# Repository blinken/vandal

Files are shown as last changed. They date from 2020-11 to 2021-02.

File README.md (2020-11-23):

# vandal
### A lighting and fan control system for campervans (or anything else)

vandal is an ESP32-based 10-channel smart switch module with LoRa, CANBus, a
display, and a rotary encoder. For 12-24V DC systems, intended to control
camper or RV lighting. It features

 * 7 switched-positive output channels, capable of each sourcing 5A at Vin (up to 27V) . All channels support fade, blink, breathe modes via an SX1509 driver.
 * 3 switched-negative channels, capable of each sinking 200mA at up to 30V.
 * 6 protected IO lines, 5V-tolerant and operating at a 3.3V logic level
 * CANBus interface (via a SN65HVD230 transceiver)
 * Protected 1Wire bus, operating at 5V, for temperature sensors (DS1820B and others)
 * LoRa transceiver (HopeRF RFM95) with SMA antenna connection
 * USB programming for the ESP32 (using a FT232R)
 * Numeric/text display: footprints and headers to support 2x [Adafruit 0.54" LED backpacks](https://learn.adafruit.com/adafruit-led-backpack/0-54-alphanumeric) 
 * 8x32 LED matrix: footprints and headers to support 4x MAX7219-based 8x8 LED arrays [Amazon](https://amzn.to/3kYg7Mb) [AliExpress 1](https://www.aliexpress.com/item/32580532205.html) [AliExpress 2](https://www.aliexpress.com/item/33038259447.html)
 * Rotary (quadrature) encoder to allow control by the user
 * Protected power supply supporting 12V and 24V lead-acid and LiFePO4 battery systems

Protected lines feature diode clamping to 5V and 0V, and high-current lines
include TVS diodes on the output to protect against overvoltage and back-EMF.
The input has reverse polarity protection. All outputs (and the input) are
individually fused.

This project is a work in progress, and the software for the ESP32 doesn't
exist yet. It's intended to control LED lighting in my van, and is a bit of an
excuse to play with CANBus and the RFM95 LoRa module.

The PCB was created in KiCad. I have a few spare - if you're interested, [shoot
me an email](mailto:blinken@gmail.com) and I can post you one for a small fee.
Alternatively, the gerber files are available [here](https://github.com/blinken/vandal/blob/main/pcb/van-1.0-gerber/van.zip).

The hardware and software for this project are copyright 2020 Patrick Coleman.
They are released under the GNU General Public License, version 3.0.

## Schematic and board renders

See this [spreadsheet](https://docs.google.com/spreadsheets/d/1M1I1nklSd06B-7MHDgoApl8QgARcywJm6RRHqY701iw/edit?usp=sharing) for the BOM for board revision v1.0.

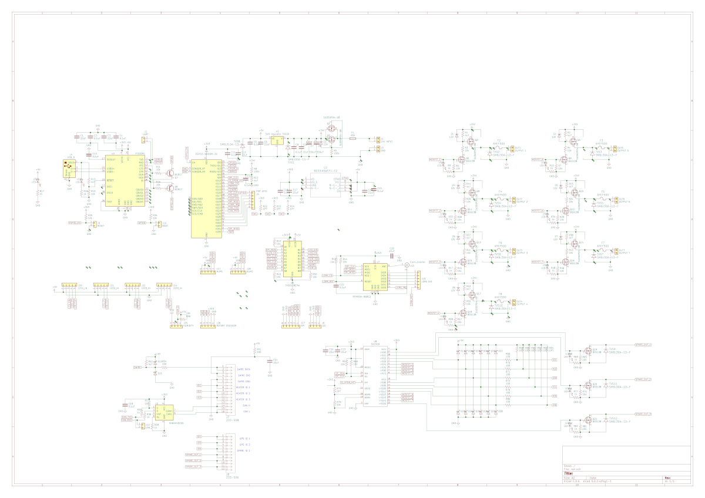
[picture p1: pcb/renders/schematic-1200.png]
schematic

[Full size PNG](https://raw.githubusercontent.com/blinken/vandal/main/pcb/renders/schematic.png) [PDF](https://github.com/blinken/vandal/raw/main/pcb/renders/schematic.pdf)

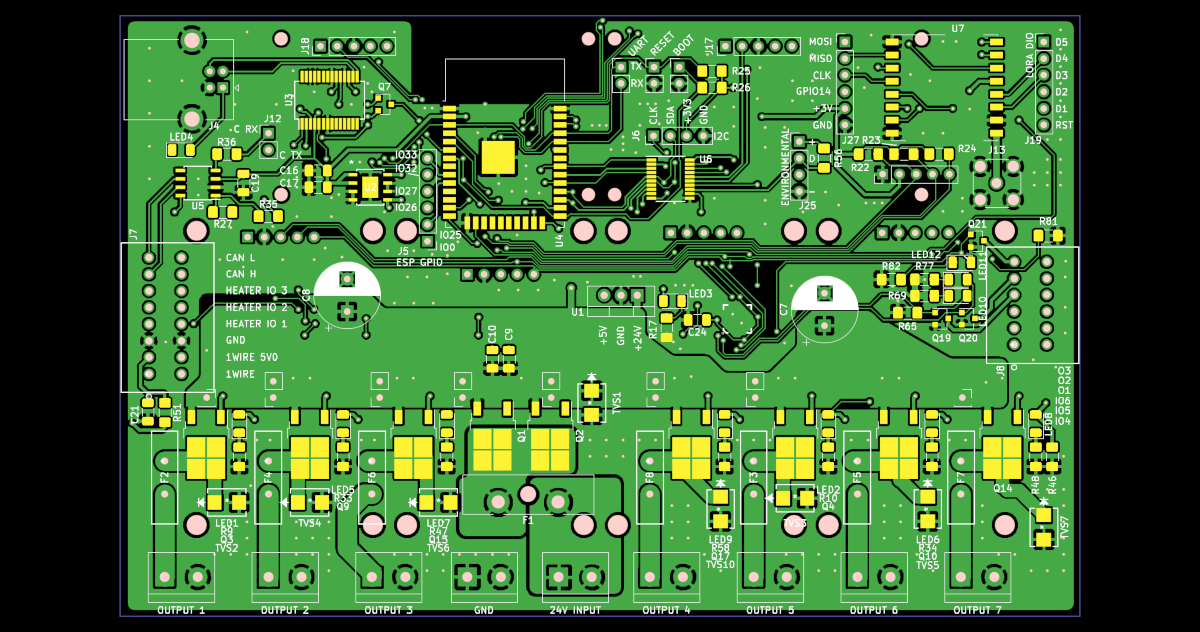
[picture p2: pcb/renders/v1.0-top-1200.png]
board top

[Full size PNG](https://raw.githubusercontent.com/blinken/vandal/main/pcb/renders/v1.0-top.png)

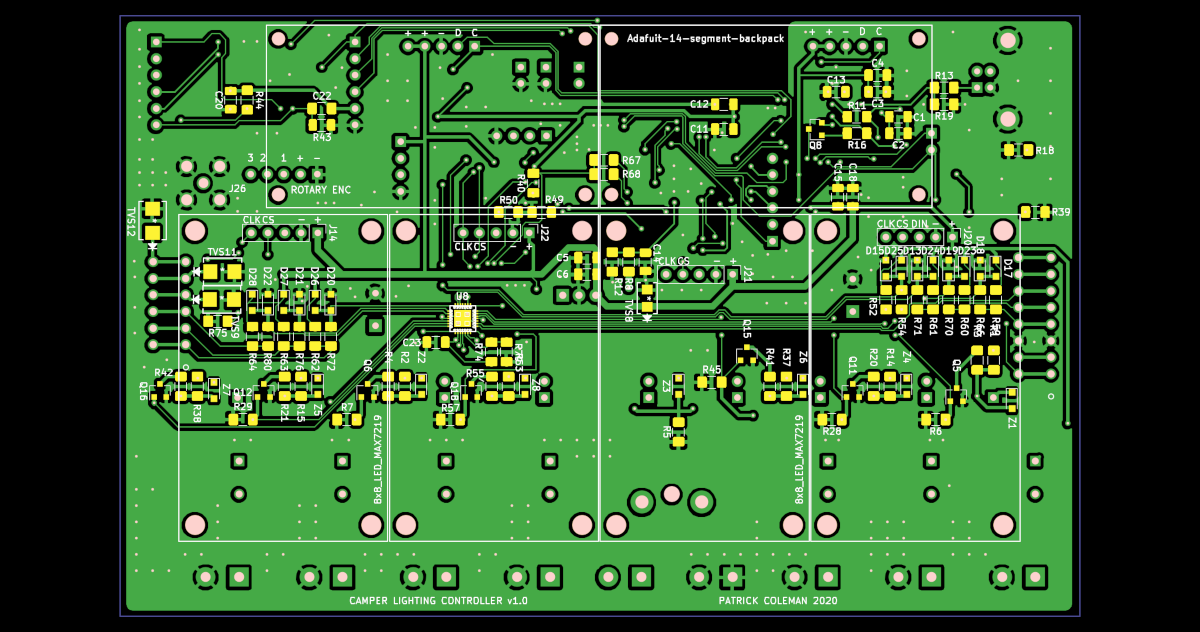
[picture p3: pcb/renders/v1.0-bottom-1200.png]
board bottom

[Full size PNG](https://raw.githubusercontent.com/blinken/vandal/main/pcb/renders/v1.0-bottom.png)

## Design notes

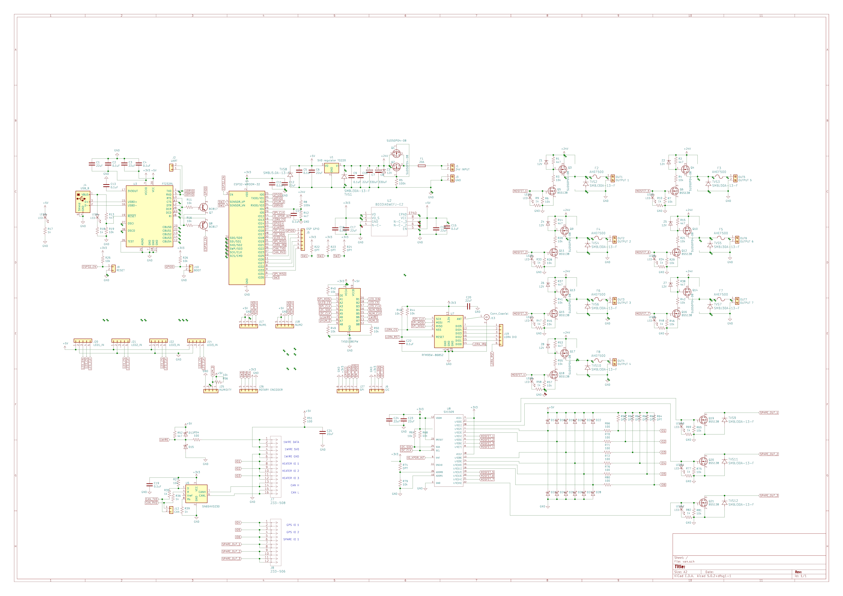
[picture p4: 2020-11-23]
pcb/renders/schematic.png

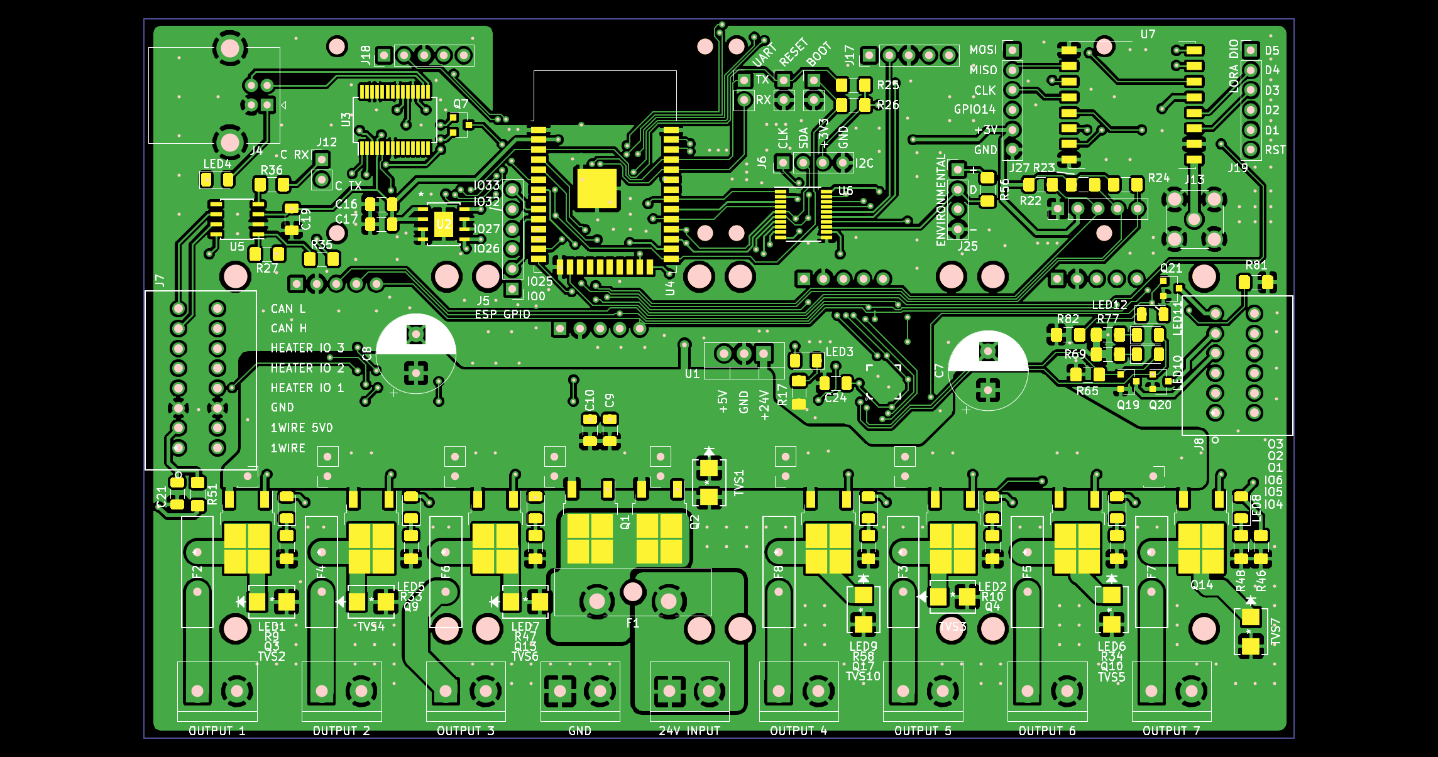
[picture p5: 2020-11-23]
pcb/renders/v1.0-top.png

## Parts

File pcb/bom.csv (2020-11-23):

Id | Designator | Package | Quantity | Designation | Supplier and ref
1 | REF**,REF**,REF**,REF** | 8x8_LED_module | 4 | 8x8_LED_MAX7219
2 | REF**,REF** | Adafuit-14-segment-backpack | 2 | Adafuit-14-segment-backpack
3 | REF**,REF**,REF**,REF**,REF**,REF** | PinSocket_1x02_P2.54mm_Vertical | 6 | PinSocket_1x02_P2.54mm_Vertical
4 | REF**,REF** | PinSocket_1x01_P2.54mm_Vertical | 2 | PinSocket_1x01_P2.54mm_Vertical
5 | C24,C23,C10,C1,C3,C6,C12,C17,C18,C20,C21 | C_1206_3216Metric | 11 | 22uF
6 | U8 | QFN-28 | 1 | SX1509
7 | J6 | PinHeader_1x04_P2.54mm_Vertical | 1 | I2C
8 | J5 | PinHeader_1x06_P2.54mm_Vertical | 1 | ESP GPIO
9 | D19,D20,D21,D22,D23,D24,D25,D18,D26,D17,D28,D27,D15,D13 | D_SOD-323_HandSoldering | 14 | D_Schottky
10 | LED11,LED10,LED12,LED3,LED1,LED5,LED4,LED6,LED7,LED8,LED9,LED2 | LED_1206_3216Metric | 12 | LED
11 | Q21,Q20,Q19,Q12,Q11,Q18,Q15,Q6,Q16,Q5 | SOT-23 | 10 | BSS138
12 | R80,R66,R71,R72,R76,R70,R54,R51 | R_1206_3216Metric_Pad1.42x1.75mm_HandSolder | 8 | 100
13 | R68,R67,R65,R75,R79,R81,R19,R16,R11,R7,R4,R20,R21,R25,R26,R27,R6,R29,R28,R55,R56,R57,R40,R41,R46,R49,R50,R45,R44,R43,R3,R42 | R_1206_3216Metric_Pad1.42x1.75mm_HandSolder | 32 | 10k
14 | R60,R61,R62,R63,R64,R59,R74,R22,R23,R24 | R_1206_3216Metric_Pad1.42x1.75mm_HandSolder | 10 | OPT
15 | R69,R77,R82,R10,R9,R18,R17,R58,R39,R36,R35,R34,R33,R47,R48 | R_1206_3216Metric_Pad1.42x1.75mm_HandSolder | 15 | 1k
16 | TVS12,TVS11,TVS9,TVS3,TVS1,TVS2,TVS10,TVS7,TVS6,TVS5,TVS4 | SMBJ30A-13-F | 11 | SMBJ30A-13-F
17 | J8 | 233-506 | 1 | 233-506
18 | J7 | 233-508 | 1 | 233-508
19 | U1 | TO-220-3_Vertical | 1 | 5V0 regulator TO220
20 | J14,J22 | PinHeader_1x05_P2.54mm_Vertical | 2 | LED3_IN
21 | U2 | BD33IA5WEFJ-E2 | 1 | BD33IA5WEFJ-E2
22 | C2,C4,C5,C9,C11,C13,C14,C15,C16,C19,C22 | C_1206_3216Metric | 11 | 0.1uF
23 | C8,C7 | CP_Radial_D10.0mm_P5.00mm | 2 | 330uF
24 | J13 | SMA_Amphenol_132134_Vertical | 1 | Conn_Coaxial
25 | J12 | PinHeader_1x02_P2.54mm_Vertical | 1 | CAN
26 | J9 | PinHeader_1x02_P2.54mm_Vertical | 1 | RESET
27 | J2 | PinHeader_1x02_P2.54mm_Vertical | 1 | UART
28 | J10 | PinHeader_1x02_P2.54mm_Vertical | 1 | BOOT
29 | J25 | PinHeader_1x04_P2.54mm_Vertical | 1 | HUMIDITY
30 | J26 | PinHeader_1x05_P2.54mm_Vertical | 1 | ROTARY ENCODER
31 | J17 | PinHeader_1x05_P2.54mm_Vertical | 1 | NUM1
32 | J18 | PinHeader_1x05_P2.54mm_Vertical | 1 | NUM2
33 | J20 | PinHeader_1x05_P2.54mm_Vertical | 1 | LED1_IN
34 | J21 | PinHeader_1x05_P2.54mm_Vertical | 1 | LED2_IN
35 | J27 | PinHeader_1x06_P2.54mm_Vertical | 1 | SPI
36 | J19 | PinHeader_1x06_P2.54mm_Vertical | 1 | LORA DIO
37 | J4 | USB_B_OST_USB-B1HSxx_Horizontal | 1 | USB_B
38 | Z5,Z7,Z6,Z4,Z3,Z2,Z1,Z8 | D_SOD-323_HandSoldering | 8 | 12V
39 | F1 | Fuseholder_Blade_ATO_Littelfuse_Pudenz_2_Pin | 1 | 20A
40 | U5 | SOIC-8_3.9x4.9mm_P1.27mm | 1 | SN65HVD230
41 | U3 | SSOP-28_5.3x10.2mm_P0.65mm | 1 | FT232RL
42 | U6 | TSSOP-20_4.4x6.5mm_P0.65mm | 1 | TXS0108EPW
43 | Q8,Q7 | SOT-23 | 2 | BC817
44 | Q9,Q14,Q17,Q10,Q4,Q3,Q2,Q1,Q13 | TO-252-2 | 9 | SUD50P04-08
45 | U4 | ESP32-WROOM-32 | 1 | ESP32-WROOM-32
46 | U7 | HOPERF_RFM9XW_SMD | 1 | RFM95W-868S2
47 | R15,R1,R13,R12,R14,R53,R38,R37,R52,R2 | R_1206_3216Metric_Pad1.42x1.75mm_HandSolder | 10 | 4k7
48 | R8,R5 | R_1206_3216Metric_Pad1.42x1.75mm_HandSolder | 2 | 100k
49 | OUT6 | TerminalBlock_bornier-2_P5.08mm | 1 | OUTPUT 6
50 | J3 | TerminalBlock_bornier-2_P5.08mm | 1 | GND
51 | OUT5 | TerminalBlock_bornier-2_P5.08mm | 1 | OUTPUT 5
52 | J1 | TerminalBlock_bornier-2_P5.08mm | 1 | 24V INPUT
53 | OUT7 | TerminalBlock_bornier-2_P5.08mm | 1 | OUTPUT 7
54 | OUT4 | TerminalBlock_bornier-2_P5.08mm | 1 | OUTPUT 4
55 | OUT3 | TerminalBlock_bornier-2_P5.08mm | 1 | OUTPUT 3
56 | OUT2 | TerminalBlock_bornier-2_P5.08mm | 1 | OUTPUT 2
57 | OUT1 | TerminalBlock_bornier-2_P5.08mm | 1 | OUTPUT 1
58 | TVS8 | SMBJ5.0A-E3&slash_52 | 1 | SMBJ5.0A-13-F
59 | F2,F8,F7,F6,F4,F3,F5 | AHEF500 | 7 | AHEF500

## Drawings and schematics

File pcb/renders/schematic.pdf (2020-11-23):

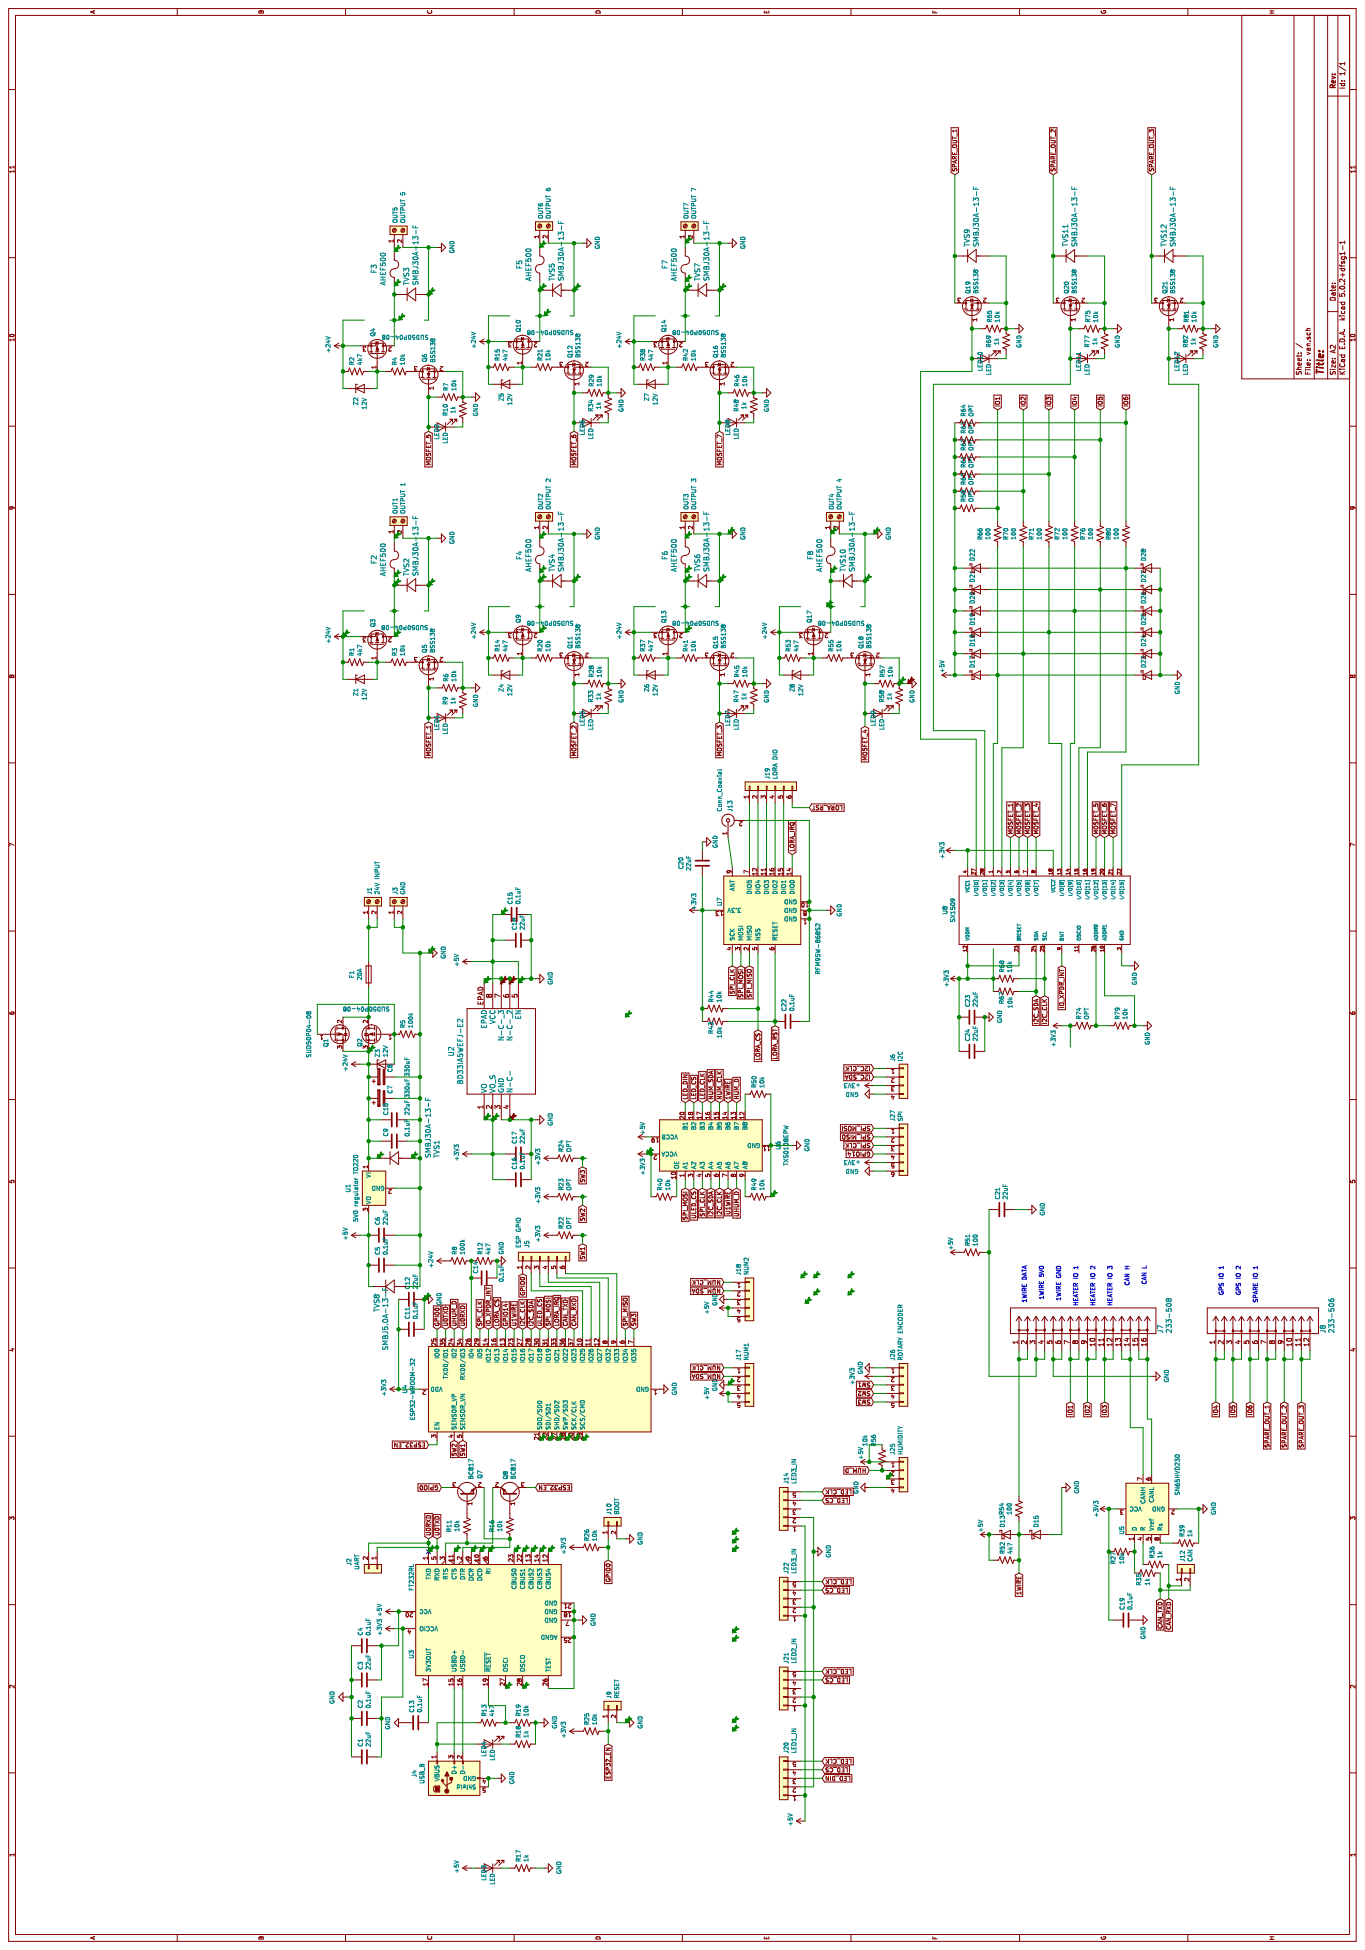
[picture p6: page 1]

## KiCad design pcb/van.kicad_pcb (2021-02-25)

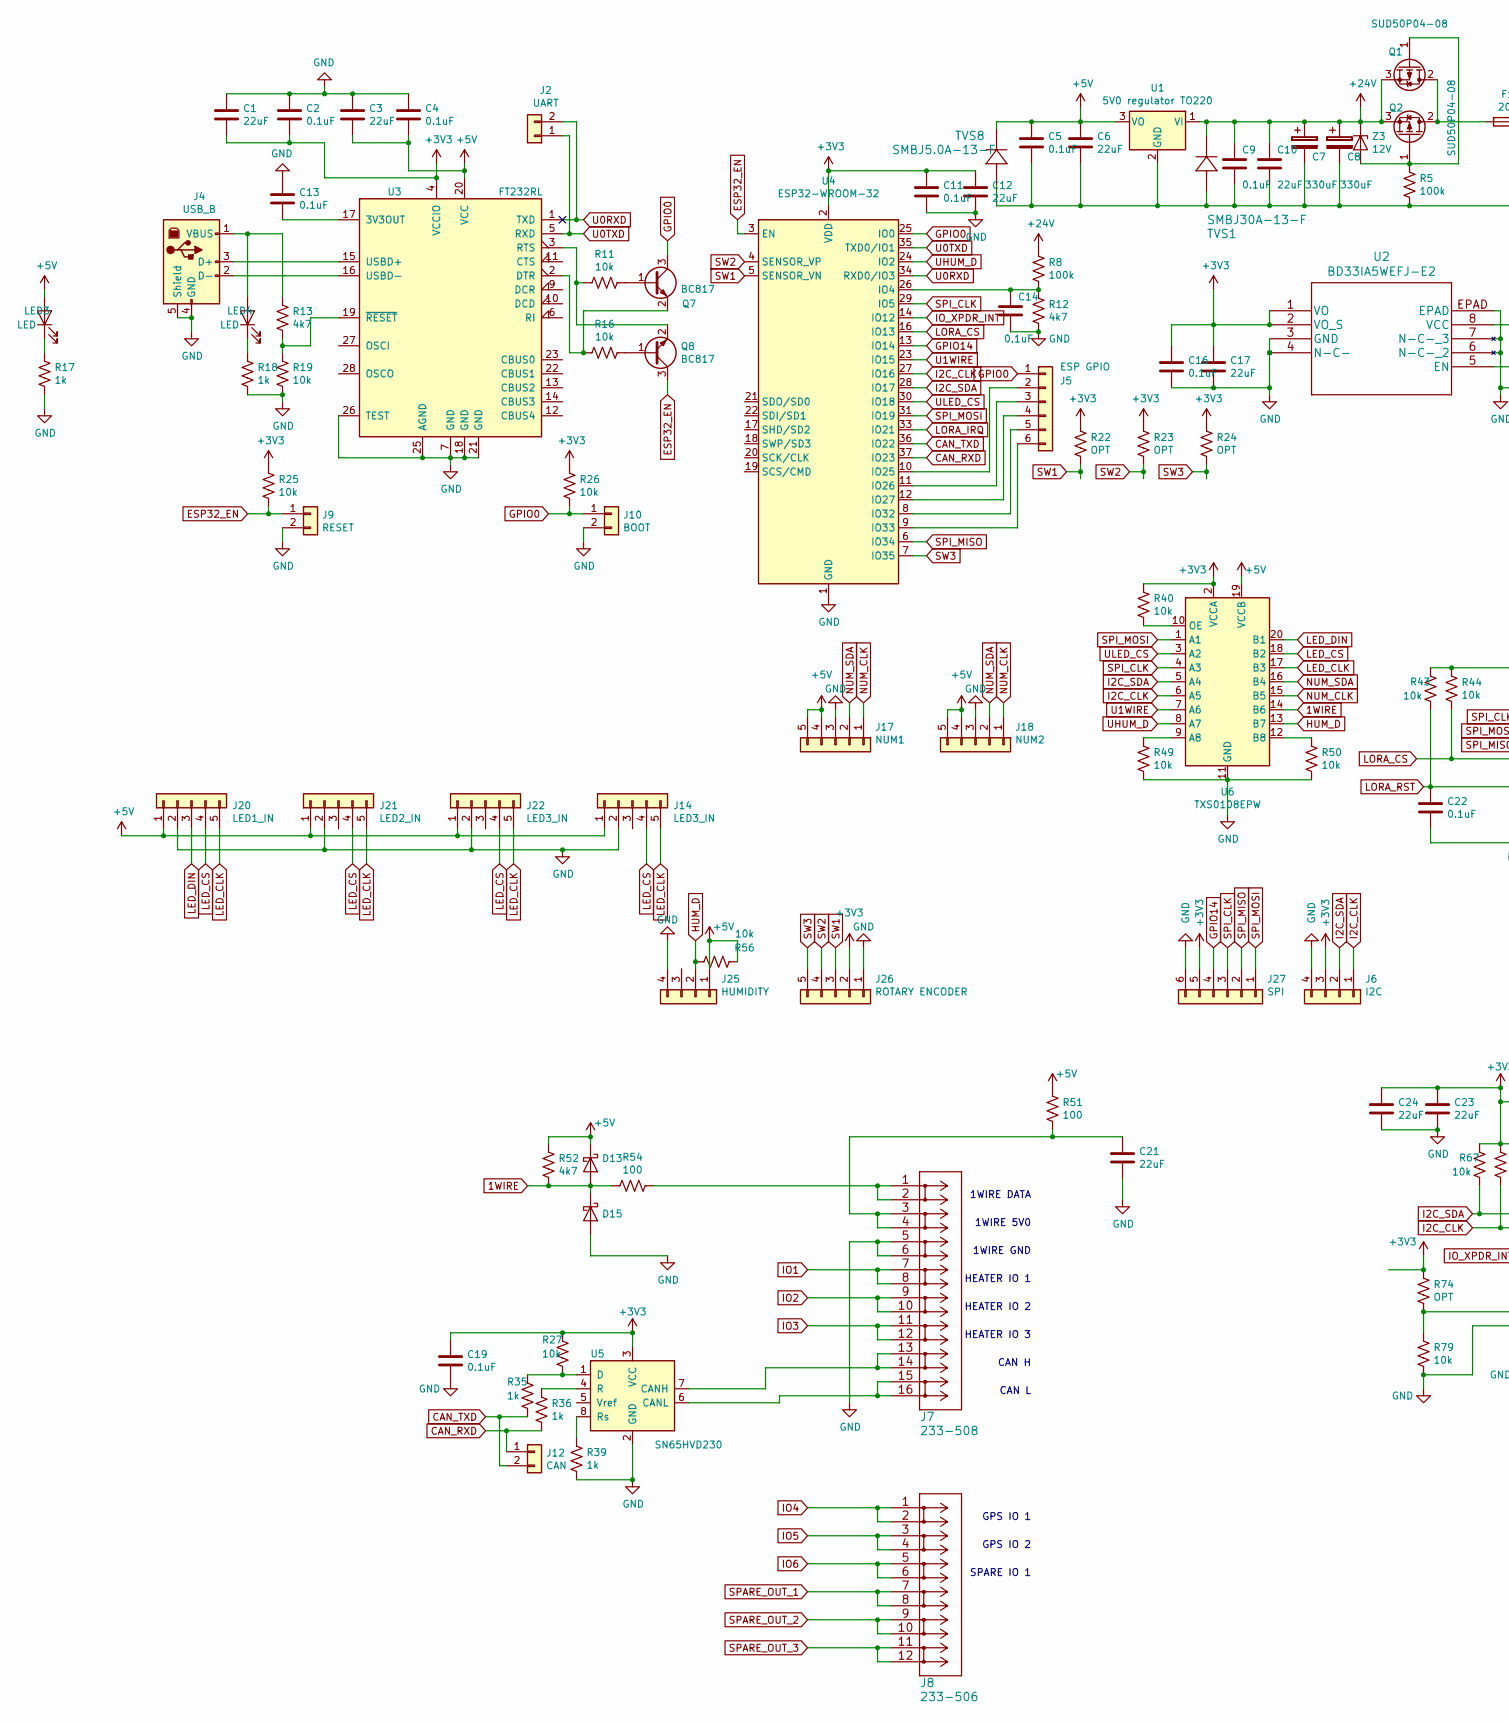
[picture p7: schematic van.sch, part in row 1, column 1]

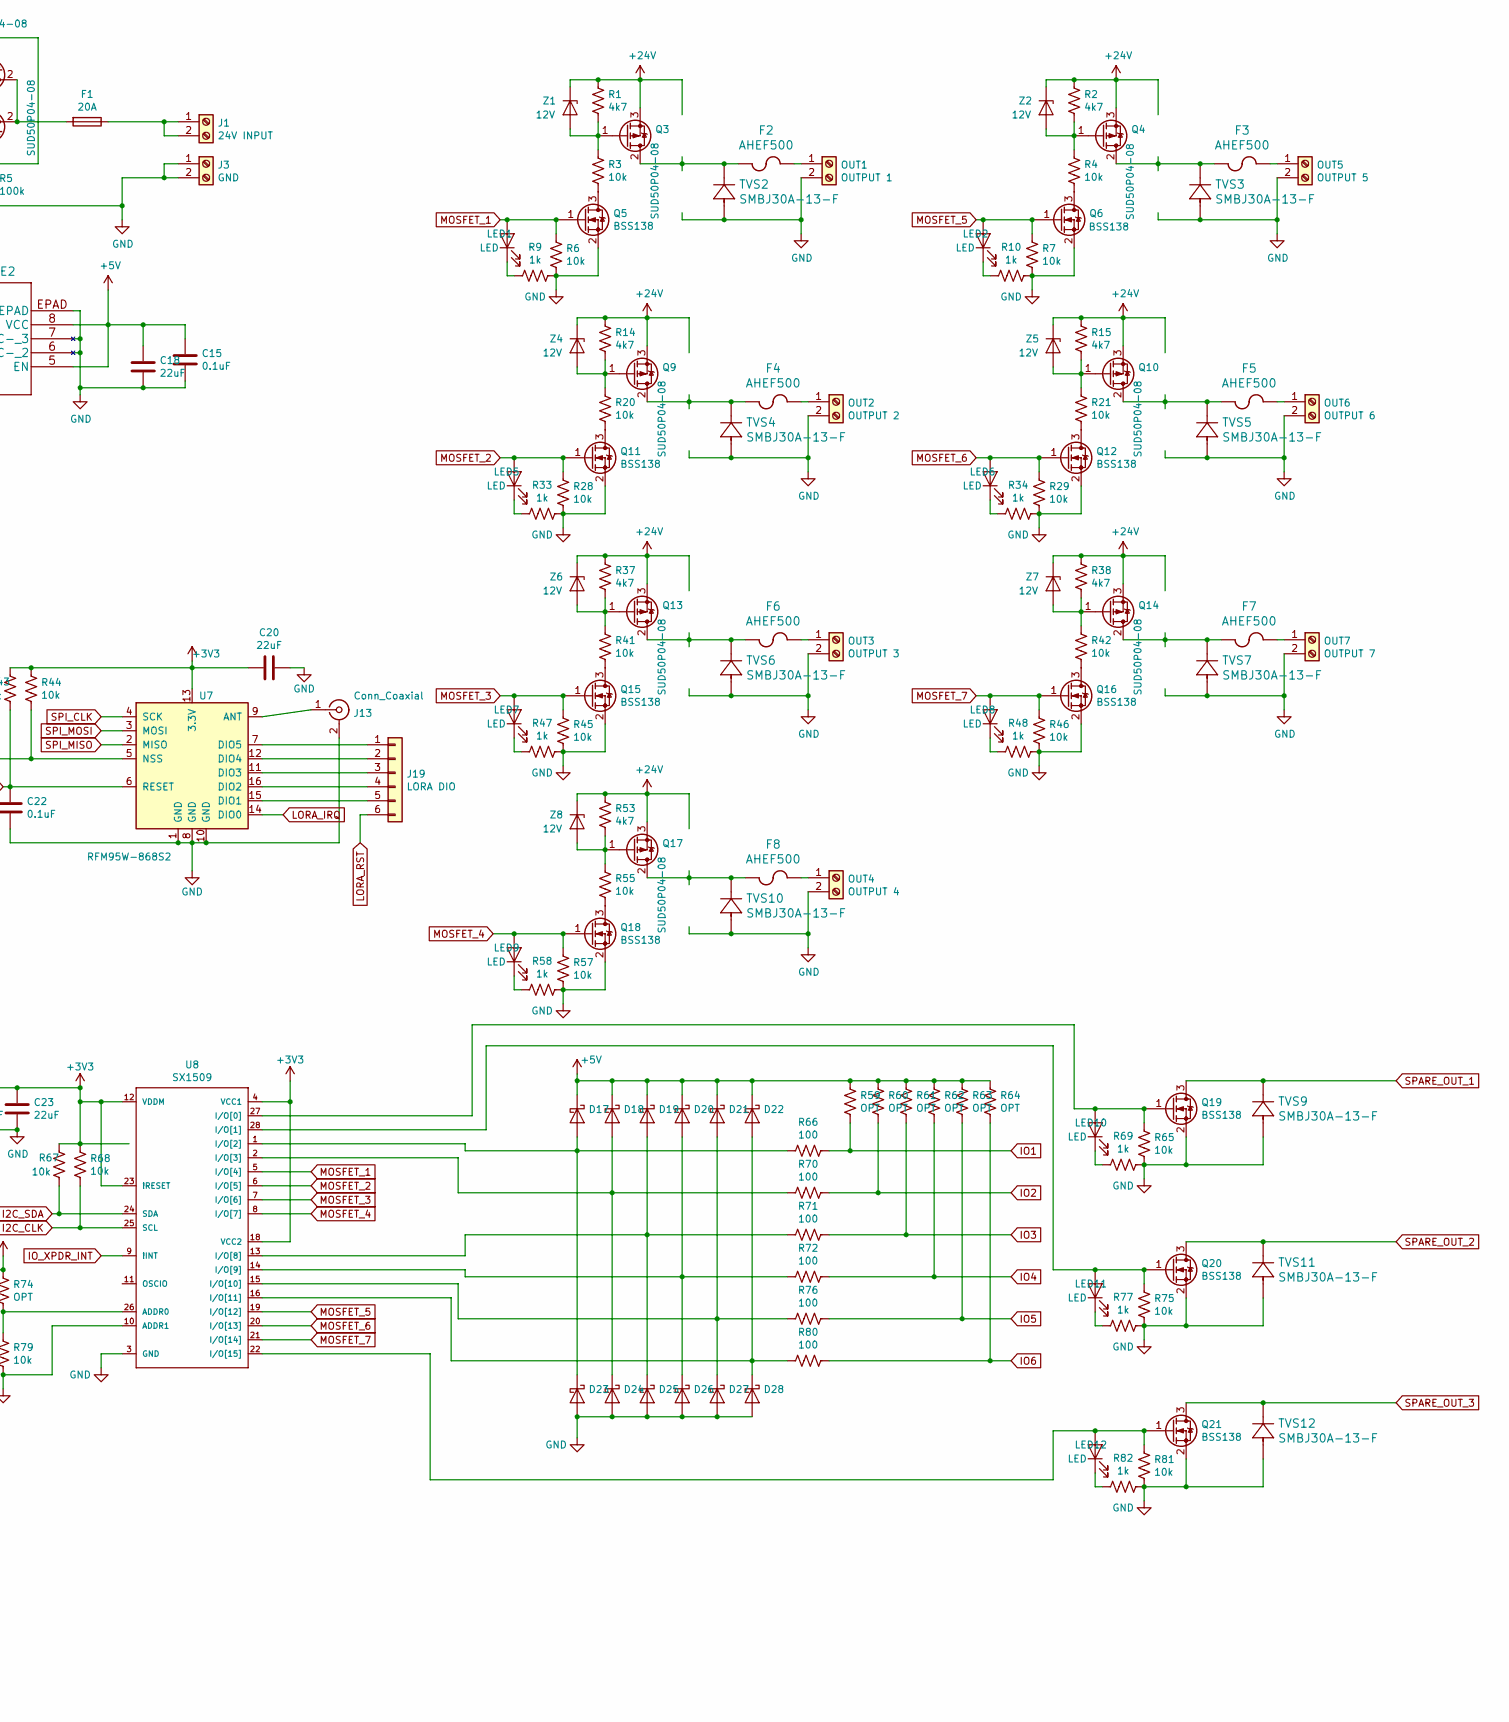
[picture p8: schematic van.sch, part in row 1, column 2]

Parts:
C1, C3, C6, C10, C12, C17, C18, C20, C21, C23, C24: 22uF; C_1206_3216Metric
C2, C4, C5, C9, C11, C13, C14, C15, C16, C19, C22: 0.1uF; C_1206_3216Metric
C7, C8: 330uF; CP_Radial_D10.0mm_P5.00mm
D13, D15, D17, D18, D19, D20, D21, D22, D23, D24, D25, D26, D27, D28: D_Schottky; D_SOD-323_HandSoldering
F1: 20A; Fuseholder_Blade_ATO_Littelfuse_Pudenz_2_Pin
F2, F3, F4, F5, F6, F7, F8: AHEF500
J1: 24V INPUT; TerminalBlock_bornier-2_P5.08mm
J2: UART; PinHeader_1x02_P2.54mm_Vertical
J3: GND; TerminalBlock_bornier-2_P5.08mm
J4: USB_B; USB_B_OST_USB-B1HSxx_Horizontal
J5: ESP GPIO; PinHeader_1x06_P2.54mm_Vertical
J6: I2C; PinHeader_1x04_P2.54mm_Vertical
J7: 233-508
J8: 233-506
J9: RESET; PinHeader_1x02_P2.54mm_Vertical
J10: BOOT; PinHeader_1x02_P2.54mm_Vertical
J12: CAN; PinHeader_1x02_P2.54mm_Vertical
J13: Conn_Coaxial; SMA_Amphenol_132134_Vertical
J14, J22: LED3_IN; PinHeader_1x05_P2.54mm_Vertical
J17: NUM1; PinHeader_1x05_P2.54mm_Vertical
J18: NUM2; PinHeader_1x05_P2.54mm_Vertical
J19: LORA DIO; PinHeader_1x06_P2.54mm_Vertical
J20: LED1_IN; PinHeader_1x05_P2.54mm_Vertical
J21: LED2_IN; PinHeader_1x05_P2.54mm_Vertical
J25: HUMIDITY; PinHeader_1x04_P2.54mm_Vertical
J26: ROTARY ENCODER; PinHeader_1x05_P2.54mm_Vertical
J27: SPI; PinHeader_1x06_P2.54mm_Vertical
LED1, LED2, LED3, LED4, LED5, LED6, LED7, LED8, LED9, LED10, LED11, LED12: LED; LED_1206_3216Metric
OUT1: OUTPUT 1; TerminalBlock_bornier-2_P5.08mm
OUT2: OUTPUT 2; TerminalBlock_bornier-2_P5.08mm
OUT3: OUTPUT 3; TerminalBlock_bornier-2_P5.08mm
OUT4: OUTPUT 4; TerminalBlock_bornier-2_P5.08mm
OUT5: OUTPUT 5; TerminalBlock_bornier-2_P5.08mm
OUT6: OUTPUT 6; TerminalBlock_bornier-2_P5.08mm
OUT7: OUTPUT 7; TerminalBlock_bornier-2_P5.08mm
Q1, Q2, Q3, Q4, Q9, Q10, Q13, Q14, Q17: SUD50P04-08; TO-252-2
Q5, Q6, Q11, Q12, Q15, Q16, Q18, Q19, Q20, Q21: BSS138; SOT-23
Q7, Q8: BC817; SOT-23
R1, R2, R12, R13, R14, R15, R37, R38, R52, R53: 4k7; R_1206_3216Metric_Pad1.42x1.75mm_HandSolder
R3, R4, R6, R7, R11, R16, R19, R20, R21, R25, R26, R27, R28, R29, R40, R41, R42, R43, R44, R45, R46, R49, R50, R55, R56, R57, R65, R67, R68, R75, R79, R81: 10k; R_1206_3216Metric_Pad1.42x1.75mm_HandSolder
R5, R8: 100k; R_1206_3216Metric_Pad1.42x1.75mm_HandSolder
R9, R10, R17, R18, R33, R34, R35, R36, R39, R47, R48, R58, R69, R77, R82: 1k; R_1206_3216Metric_Pad1.42x1.75mm_HandSolder
R22, R23, R24, R59, R60, R61, R62, R63, R64, R74: OPT; R_1206_3216Metric_Pad1.42x1.75mm_HandSolder
R51, R54, R66, R70, R71, R72, R76, R80: 100; R_1206_3216Metric_Pad1.42x1.75mm_HandSolder
TVS1, TVS2, TVS3, TVS4, TVS5, TVS6, TVS7, TVS9, TVS10, TVS11, TVS12: SMBJ30A-13-F
TVS8: SMBJ5.0A-13-F; SMBJ5.0A-E3&slash_52
U1: 5V0 regulator TO220; TO-220-3_Vertical
U2: BD33IA5WEFJ-E2
U3: FT232RL; SSOP-28_5.3x10.2mm_P0.65mm
U4: ESP32-WROOM-32
U5: SN65HVD230; SOIC-8_3.9x4.9mm_P1.27mm
U6: TXS0108EPW; TSSOP-20_4.4x6.5mm_P0.65mm
U7: RFM95W-868S2; HOPERF_RFM9XW_SMD
U8: SX1509; QFN-28
Z1, Z2, Z3, Z4, Z5, Z6, Z7, Z8: 12V; D_SOD-323_HandSoldering

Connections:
1WIRE: D13.2 (A), D15.1 (K), R52.2, R54.2, U6.14 (B6)
+3V3: C1.2, C2.2, C11.1, C12.1, C16.1, C17.1, C19.1, C20.2, C23.2, C24.2, J6.3, J26.2, J27.5, R22.2, R23.2, R24.2, R25.2, R26.2, R27.1, R40.1, R43.1, R44.1, R67.2, R68.2, R74.2, U2.1 (VO), U2.2 (VO_S), U3.4 (VCCIO), U4.2 (VDD), U5.3 (VCC), U6.2 (VCCA), U7.13 (3.3V), U8.4 (VCC1), U8.12 (VDDM), U8.18 (VCC2), U8.23 (!RESET)
+5V: C3.2, C4.2, C5.1, C6.1, C15.1, C18.1, D13.1 (K), D17.1 (K), D18.1 (K), D19.1 (K), D20.1 (K), D21.1 (K), D22.1 (K), J14.1, J17.4, J17.5, J18.4, J18.5, J20.1, J21.1, J22.1, J25.1, LED3.2 (A), R51.2, R52.1, R56.1, R59.2, R60.2, R61.2, R62.2, R63.2, R64.2, TVS8.1, U1.3 (VO), U2.5 (EN), U2.8 (VCC), U3.20 (VCC), U6.19 (VCCB)
+24V: C7.1, C8.1, C9.1, C10.1, Q1.3 (S), Q2.3 (S), Q3.3 (S), Q4.3 (S), Q9.3 (S), Q10.3 (S), Q13.3 (S), Q14.3 (S), Q17.3 (S), R1.1, R2.1, R8.1, R14.1, R15.1, R37.1, R38.1, R53.1, TVS1.1, U1.1 (VI), Z1.1 (K), Z2.1 (K), Z3.1 (K), Z4.1 (K), Z5.1 (K), Z6.1 (K), Z7.1 (K), Z8.1 (K)
CAN_RXD: J12.1, R36.2, U4.37 (IO23)
CAN_TXD: J12.2, R35.2, U4.36 (IO22)
ESP32_EN: J9.1, Q8.3 (C), R25.1, U4.3 (EN)
GND: C1.1, C2.1, C3.1, C4.1, C5.2, C6.2, C7.2, C8.2, C9.2, C10.2, C11.2, C12.2, C13.1, C14.2, C15.2, C16.2, C17.2, C18.2, C19.2, C20.1, C21.1, C22.2, C23.1, C24.1, D15.2 (A), D23.2 (A), D24.2 (A), D25.2 (A), D26.2 (A), D27.2 (A), D28.2 (A), J3.1, J3.2, J4.4 (GND), J4.5 (Shield), J6.4, J7.5, J7.6, J9.2, J10.2, J13.2 (Ext), J14.2, J17.3, J18.3, J20.2, J21.2, J22.2, J25.4, J26.1, J27.6, OUT1.2, OUT2.2, OUT3.2, OUT4.2, OUT5.2, OUT6.2, OUT7.2, Q5.2 (S), Q6.2 (S), Q11.2 (S), Q12.2 (S), Q15.2 (S), Q16.2 (S), Q18.2 (S), Q19.2 (S), Q20.2 (S), Q21.2 (S), R5.1, R6.2, R7.2, R9.1, R10.1, R12.2, R17.1, R18.1, R19.1, R28.2, R29.2, R33.1, R34.1, R39.2, R45.2, R46.2, R47.1, R48.1, R49.2, R50.2, R57.2, R58.1, R65.2, R69.1, R75.2, R77.1, R79.1, R81.2, R82.1, TVS1.2, TVS2.2, TVS3.2, TVS4.2, TVS5.2, TVS6.2, TVS7.2, TVS8.2, TVS9.2, TVS10.2, TVS11.2, TVS12.2, U1.2 (GND), U2.3 (GND), U2.4 (N-C-), U2.6 (N-C-_2), U2.7 (N-C-_3), U2.EPAD, U3.7 (GND), U3.18 (GND), U3.21 (GND), U3.25 (AGND), U3.26 (TEST), U4.1 (GND), U4.15 (GND), U4.38 (GND), U4.39, U5.2 (GND), U6.11 (GND), U7.1 (GND), U7.8 (GND), U7.10 (GND), U8.3 (GND), U8.10 (ADDR1), U8.17 (GND), U8.29 (GND)
GPIO0: J5.1, J10.1, Q7.3 (C), R26.1, U4.25 (IO0)
GPIO14: J27.4, U4.13 (IO14)
HUM_D: J25.2, R56.2, U6.13 (B7)
I2C_CLK: J6.1, R68.1, U4.27 (IO16), U6.6 (A5), U8.25 (SCL)
I2C_SDA: J6.2, R67.1, U4.28 (IO17), U6.5 (A4), U8.24 (SDA)
IO1: J7.7, J7.8, R59.1, R66.1
IO2: J7.9, J7.10, R60.1, R70.1
IO3: J7.11, J7.12, R61.1, R71.1
IO4: J8.1, J8.2, R62.1, R72.1
IO5: J8.3, J8.4, R63.1, R76.1
IO6: J8.5, J8.6, R64.1, R80.1
IO_XPDR_INT: U4.14 (IO12), U8.9 (!INT)
LED_CLK: J14.5, J20.5, J21.5, J22.5, U6.17 (B3)
LED_CS: J14.4, J20.4, J21.4, J22.4, U6.18 (B2)
LED_DIN: J20.3, U6.20 (B1)
LORA_CS: R44.2, U4.16 (IO13), U7.5 (NSS)
LORA_IRQ: U4.33 (IO21), U7.14 (DIO0)
LORA_RST: C22.1, J19.6, R43.2, U7.6 (RESET)
MOSFET_1: LED1.2 (A), Q5.1 (G), R6.1, U8.5 (I/O[4])
MOSFET_2: LED5.2 (A), Q11.1 (G), R28.1, U8.6 (I/O[5])
MOSFET_3: LED7.2 (A), Q15.1 (G), R45.1, U8.7 (I/O[6])
MOSFET_4: LED9.2 (A), Q18.1 (G), R57.1, U8.8 (I/O[7])
MOSFET_5: LED2.2 (A), Q6.1 (G), R7.1, U8.19 (I/O[12])
MOSFET_6: LED6.2 (A), Q12.1 (G), R29.1, U8.20 (I/O[13])
MOSFET_7: LED8.2 (A), Q16.1 (G), R46.1, U8.21 (I/O[14])
NUM_CLK: J17.1, J18.1, U6.15 (B5)
NUM_SDA: J17.2, J18.2, U6.16 (B4)
unnamed: C13.2, U3.17 (3V3OUT)
unnamed: C14.1, R8.2, R12.1, U4.26 (IO4)
unnamed: C21.2, J7.3, J7.4, R51.1
unnamed: D17.2 (A), D23.1 (K), R66.2, U8.1 (I/O[2])
unnamed: D18.2 (A), D24.1 (K), R70.2, U8.2 (I/O[3])
unnamed: D19.2 (A), D25.1 (K), R71.2, U8.13 (I/O[8])
unnamed: D20.2 (A), D26.1 (K), R72.2, U8.14 (I/O[9])
unnamed: D21.2 (A), D27.1 (K), R76.2, U8.15 (I/O[10])
unnamed: D22.2 (A), D28.1 (K), R80.2, U8.16 (I/O[11])
unnamed: F1.1, J1.1, J1.2
unnamed: F1.2, Q1.2 (D), Q2.2 (D)
unnamed: F2.1, Q3.2 (D), TVS2.1
unnamed: F2.2, OUT1.1
unnamed: F3.1, Q4.2 (D), TVS3.1
unnamed: F3.2, OUT5.1
unnamed: F4.1, Q9.2 (D), TVS4.1
unnamed: F4.2, OUT2.1
unnamed: F5.1, Q10.2 (D), TVS5.1
unnamed: F5.2, OUT6.1
unnamed: F6.1, Q13.2 (D), TVS6.1
unnamed: F6.2, OUT3.1
unnamed: F7.1, Q14.2 (D), TVS7.1
unnamed: F7.2, OUT7.1
unnamed: F8.1, Q17.2 (D), TVS10.1
unnamed: F8.2, OUT4.1
unnamed: J4.1 (VBUS), LED4.2 (A), R13.2
unnamed: J4.2 (D-), U3.16 (USBD-)
unnamed: J4.3 (D+), U3.15 (USBD+)
unnamed: J5.2, U4.10 (IO25)
unnamed: J5.3, U4.11 (IO26)
unnamed: J5.4, U4.12 (IO27)
unnamed: J5.5, U4.8 (IO32)
unnamed: J5.6, U4.9 (IO33)
unnamed: J7.1, J7.2, R54.1
unnamed: J7.13, J7.14, U5.7 (CANH)
unnamed: J7.15, J7.16, U5.6 (CANL)
unnamed: J13.1 (In), U7.9 (ANT)
unnamed: J19.1, U7.7 (DIO5)
unnamed: J19.2, U7.12 (DIO4)
unnamed: J19.3, U7.11 (DIO3)
unnamed: J19.4, U7.16 (DIO2)
unnamed: J19.5, U7.15 (DIO1)
unnamed: LED1.1 (K), R9.2
unnamed: LED2.1 (K), R10.2
unnamed: LED3.1 (K), R17.2
unnamed: LED4.1 (K), R18.2
unnamed: LED5.1 (K), R33.2
unnamed: LED6.1 (K), R34.2
unnamed: LED7.1 (K), R47.2
unnamed: LED8.1 (K), R48.2
unnamed: LED9.1 (K), R58.2
unnamed: LED10.1 (K), R69.2
unnamed: LED10.2 (A), Q19.1 (G), R65.1, U8.27 (I/O[0])
unnamed: LED11.1 (K), R77.2
unnamed: LED11.2 (A), Q20.1 (G), R75.1, U8.28 (I/O[1])
unnamed: LED12.1 (K), R82.2
unnamed: LED12.2 (A), Q21.1 (G), R81.1, U8.22 (I/O[15])
unnamed: Q1.1 (G), Q2.1 (G), R5.2, Z3.2 (A)
unnamed: Q3.1 (G), R1.2, R3.1, Z1.2 (A)
unnamed: Q4.1 (G), R2.2, R4.1, Z2.2 (A)
unnamed: Q5.3 (D), R3.2
unnamed: Q6.3 (D), R4.2
unnamed: Q7.1 (B), R11.2
unnamed: Q7.2 (E), R16.1, U3.2 (DTR)
unnamed: Q8.1 (B), R16.2
unnamed: Q8.2 (E), R11.1, U3.3 (RTS)
unnamed: Q9.1 (G), R14.2, R20.1, Z4.2 (A)
unnamed: Q10.1 (G), R15.2, R21.1, Z5.2 (A)
unnamed: Q11.3 (D), R20.2
unnamed: Q12.3 (D), R21.2
unnamed: Q13.1 (G), R37.2, R41.1, Z6.2 (A)
unnamed: Q14.1 (G), R38.2, R42.1, Z7.2 (A)
unnamed: Q15.3 (D), R41.2
unnamed: Q16.3 (D), R42.2
unnamed: Q17.1 (G), R53.2, R55.1, Z8.2 (A)
unnamed: Q18.3 (D), R55.2
unnamed: R13.1, R19.2, U3.19 (~RESET~)
unnamed: R27.2, R35.1, U5.1 (D)
unnamed: R36.1, U5.4 (R)
unnamed: R39.1, U5.8 (Rs)
unnamed: R40.2, U6.10 (OE)
unnamed: R49.1, U6.9 (A8)
unnamed: R50.1, U6.12 (B8)
unnamed: R74.1, R79.2, U8.26 (ADDR0)
SPARE_OUT_1: J8.7, J8.8, Q19.3 (D), TVS9.1
SPARE_OUT_2: J8.9, J8.10, Q20.3 (D), TVS11.1
SPARE_OUT_3: J8.11, J8.12, Q21.3 (D), TVS12.1
SPI_CLK: J27.3, U4.29 (IO5), U6.4 (A3), U7.4 (SCK)
SPI_MISO: J27.2, U4.6 (IO34), U7.2 (MISO)
SPI_MOSI: J27.1, U4.31 (IO19), U6.1 (A1), U7.3 (MOSI)
SW1: J26.3, R22.1, U4.5 (SENSOR_VN)
SW2: J26.4, R23.1, U4.4 (SENSOR_VP)
SW3: J26.5, R24.1, U4.7 (IO35)
U0RXD: J2.2, U3.1 (TXD), U4.34 (RXD0/IO3)
U0TXD: J2.1, U3.5 (RXD), U4.35 (TXD0/IO1)
U1WIRE: U4.23 (IO15), U6.7 (A6)
UHUM_D: U4.24 (IO2), U6.8 (A7)
ULED_CS: U4.30 (IO18), U6.3 (A2)

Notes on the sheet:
1WIRE DATA
1WIRE 5V0
1WIRE GND
HEATER IO 1
HEATER IO 2
HEATER IO 3
CAN H
CAN L
GPS IO 1
GPS IO 2
SPARE IO 1

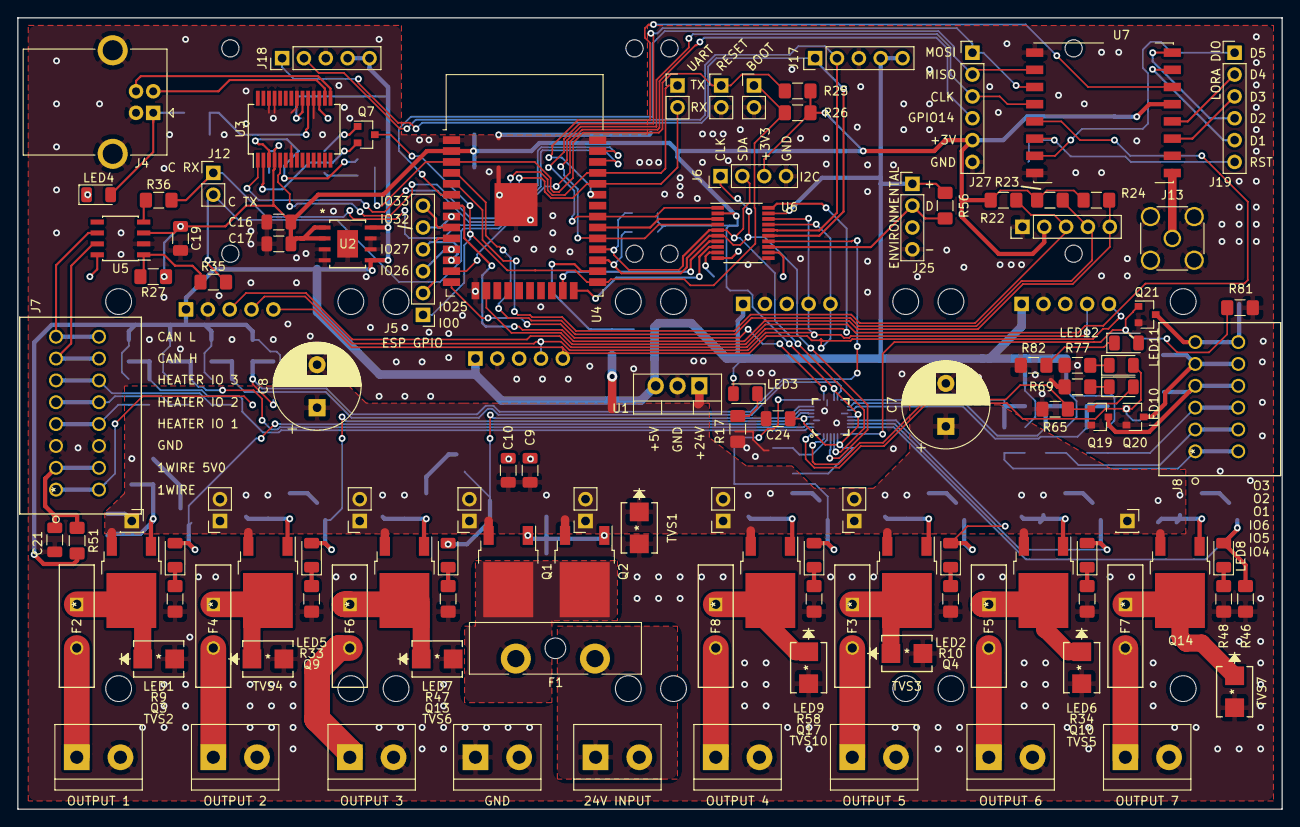
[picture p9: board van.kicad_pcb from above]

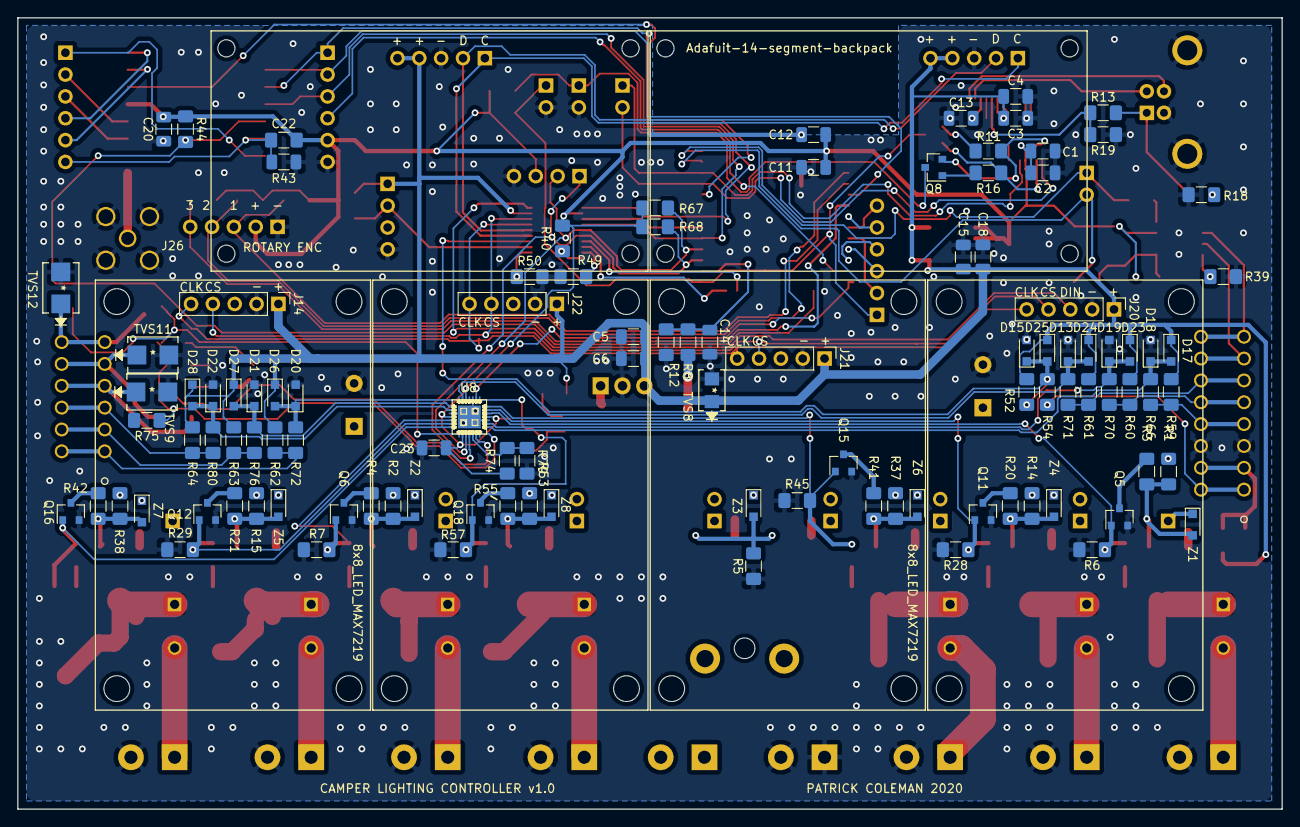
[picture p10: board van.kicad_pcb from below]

Board: 2 copper layers, 147.0 x 92.0 mm, 213 parts (107 on the bottom side), 133 nets.

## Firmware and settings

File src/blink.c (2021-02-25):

/* Blink Example
   This example code is in the Public Domain (or CC0 licensed, at your option.)
   Unless required by applicable law or agreed to in writing, this
   software is distributed on an "AS IS" BASIS, WITHOUT WARRANTIES OR
   CONDITIONS OF ANY KIND, either express or implied.
*/
#include <stdio.h>
#include <unistd.h>
#include <string.h>
#include "freertos/FreeRTOS.h"
#include "freertos/task.h"
#include "freertos/queue.h"
#include "esp_system.h"
#include "esp_err.h"
#include "driver/gpio.h"
#include "driver/i2c.h"
#include "driver/pcnt.h"
#include "16-segment-font.h"

#define I2C_ADDR_IOEXP      0x3e
#define I2C_ADDR_NUM_A      0x70
#define I2C_ADDR_NUM_B      0x71
#define I2C_SCL_GPIO				16
#define I2C_SDA_GPIO				17
#define I2C_FREQ_HZ					200000
#define I2C_WRITE_BIT				0
#define I2C_READ_BIT				1
#define I2C_ACK_CHECK_EN    true
#define I2C_WAIT            2*I2C_FREQ_HZ

bool i2c_write(uint8_t addr, uint8_t reg, uint8_t value, char *description) {

  uint8_t write_addr = (addr<<1) | I2C_WRITE_BIT;

	i2c_cmd_handle_t cmd = i2c_cmd_link_create();
	i2c_master_start(cmd);
	i2c_master_write_byte(cmd, write_addr, I2C_ACK_CHECK_EN);
	i2c_master_write_byte(cmd, reg, I2C_ACK_CHECK_EN);
	i2c_master_write_byte(cmd, value, I2C_ACK_CHECK_EN);
	i2c_master_stop(cmd);
	printf("%20s (0x%02x) = 0x%02x: ", description, reg, value);
	esp_err_t i2c_ret = i2c_master_cmd_begin(I2C_NUM_1, cmd, I2C_WAIT);	//"(# / portTICK_RATE_MS)"=maximum wait time. This task will be blocked until all the commands have been sent (not thread-safe - if you want to use one I2C port in different tasks you need to take care of multi-thread issues)
  ESP_ERROR_CHECK_WITHOUT_ABORT(i2c_ret);
  i2c_cmd_link_delete(cmd);

  if (i2c_ret == ESP_OK) {
    printf("succeeded.\n");
    return true;
  } else {
    printf("failed.\n");
    return false;
  }
}

bool i2c_setup_num(uint8_t addr) {

  uint8_t write_addr = (addr<<1) | I2C_WRITE_BIT;

	i2c_cmd_handle_t cmd = i2c_cmd_link_create();
	i2c_master_start(cmd);
	i2c_master_write_byte(cmd, write_addr, I2C_ACK_CHECK_EN);
	i2c_master_write_byte(cmd, 0x21, I2C_ACK_CHECK_EN); // system setup
	i2c_master_stop(cmd);
	esp_err_t i2c_ret = i2c_master_cmd_begin(I2C_NUM_1, cmd, I2C_WAIT);
  ESP_ERROR_CHECK_WITHOUT_ABORT(i2c_ret);
  i2c_cmd_link_delete(cmd);

	cmd = i2c_cmd_link_create();
	i2c_master_start(cmd);
	i2c_master_write_byte(cmd, write_addr, I2C_ACK_CHECK_EN);
	i2c_master_write_byte(cmd, 0xA0, I2C_ACK_CHECK_EN); // row/int setup
	i2c_master_stop(cmd);
	i2c_ret = i2c_master_cmd_begin(I2C_NUM_1, cmd, I2C_WAIT);
  ESP_ERROR_CHECK_WITHOUT_ABORT(i2c_ret);
  i2c_cmd_link_delete(cmd);

	cmd = i2c_cmd_link_create();
	i2c_master_start(cmd);
	i2c_master_write_byte(cmd, write_addr, I2C_ACK_CHECK_EN);
	i2c_master_write_byte(cmd, 0x81, I2C_ACK_CHECK_EN); // display setup
	i2c_master_stop(cmd);
	i2c_ret = i2c_master_cmd_begin(I2C_NUM_1, cmd, I2C_WAIT);
  ESP_ERROR_CHECK_WITHOUT_ABORT(i2c_ret);
  i2c_cmd_link_delete(cmd);


	cmd = i2c_cmd_link_create();
	i2c_master_start(cmd);
	i2c_master_write_byte(cmd, write_addr, I2C_ACK_CHECK_EN);
	i2c_master_write_byte(cmd, 0xEF, I2C_ACK_CHECK_EN); // full brightness
	i2c_master_stop(cmd);
	i2c_ret = i2c_master_cmd_begin(I2C_NUM_1, cmd, I2C_WAIT);
  ESP_ERROR_CHECK_WITHOUT_ABORT(i2c_ret);
  i2c_cmd_link_delete(cmd);


  if (i2c_ret == ESP_OK) {
    printf("Setup num %02x succeeded.\n", addr);
    return true;
  } else {
    printf("Setup num %02x failed.\n", addr);
    return false;
  }
}

bool i2c_update_num(uint8_t addr, uint8_t *buf, int len) {
  uint8_t write_addr = (addr<<1) | I2C_WRITE_BIT;

	i2c_cmd_handle_t cmd = i2c_cmd_link_create();
	i2c_master_start(cmd);
	i2c_master_write_byte(cmd, write_addr, I2C_ACK_CHECK_EN);
	i2c_master_write_byte(cmd, 0x00, I2C_ACK_CHECK_EN);

  if (len>4)
    len=4;

  for (int i=0; i<len; i++) {
    i2c_master_write_byte(cmd, (uint8_t)(alphafonttable[buf[i]]) & 0xff, I2C_ACK_CHECK_EN);
    i2c_master_write_byte(cmd, (uint8_t)(alphafonttable[buf[i]]) >> 8, I2C_ACK_CHECK_EN);
  }

	i2c_master_stop(cmd);

	esp_err_t i2c_ret = i2c_master_cmd_begin(I2C_NUM_1, cmd, I2C_WAIT);
  ESP_ERROR_CHECK_WITHOUT_ABORT(i2c_ret);
  i2c_cmd_link_delete(cmd);

  if (i2c_ret == ESP_OK) {
    printf("Buffer update %02x succeeded.\n", addr);
    return true;
  } else {
    printf("Buffer update %02x failed.\n", addr);
    return false;
  }
}

bool i2c_write_ioexp(uint8_t reg, uint8_t value, char *description) {
  return i2c_write(I2C_ADDR_IOEXP, reg, value, description);
}

bool i2c_write_num_a(uint8_t reg, uint8_t value, char *description) {
  return i2c_write(I2C_ADDR_NUM_A, reg, value, description);
}

bool i2c_write_num_b(uint8_t reg, uint8_t value, char *description) {
  return i2c_write(I2C_ADDR_NUM_B, reg, value, description);
}

void num_config() {
  i2c_setup_num(I2C_ADDR_NUM_A);
  i2c_setup_num(I2C_ADDR_NUM_B);

  uint8_t buf_a[4] = "abcd", buf_b[4] = "abcd";
  //memset(buf_a, 0xaa, sizeof(buf_a));
  //memset(buf_b, 0xff, sizeof(buf_b));

  // First digit on
  i2c_update_num(I2C_ADDR_NUM_A, buf_a, sizeof(buf_a));
  i2c_update_num(I2C_ADDR_NUM_B, buf_b, sizeof(buf_b));
}

void i2c_setup() {
	i2c_config_t conf;
	conf.mode = I2C_MODE_MASTER;
	conf.sda_io_num = 17;
	conf.sda_pullup_en = GPIO_PULLUP_ENABLE;
	conf.scl_io_num = 16;
	conf.scl_pullup_en = GPIO_PULLUP_ENABLE;
	conf.master.clk_speed = I2C_FREQ_HZ;
	i2c_param_config(I2C_NUM_1, &conf);
	i2c_driver_install(I2C_NUM_1, conf.mode, 0, 0, 0);
}

void ioexp_config() {
  i2c_write_ioexp(0x01, 0xff, "regInputDisableA");
  i2c_write_ioexp(0x09, 0xff, "regPullDownA");
  i2c_write_ioexp(0x0b, 0x00, "regOpenDrainA"); // disabled - push pull operation
  i2c_write_ioexp(0x0f, 0x00, "regDirA");
  i2c_write_ioexp(0x1e, 0x40, "regClock");
  i2c_write_ioexp(0x1f, 0x30, "regMisc"); // set LED clock to 2Mhz/(2^^3-1)
  i2c_write_ioexp(0x21, 0xff, "regLedDriverEnableA");
  i2c_write_ioexp(0x0d, 0x00, "regPolarityA"); // explicitly set polarities - on startup, these seem to be inverted (0xff)
  i2c_write_ioexp(0x0c, 0x00, "regPolarityB");

  // MOSFET1 - breathe when off
  i2c_write_ioexp(0x35, 0x0f, "regTOn4");
  i2c_write_ioexp(0x36, 0xff, "regTIOn4");
  i2c_write_ioexp(0x37, 0x0f, "regOff4");
  i2c_write_ioexp(0x38, 0x0f, "regTRise4");
  i2c_write_ioexp(0x39, 0x0f, "regTFall4");

  // MOSFET2 - breathe when off
  i2c_write_ioexp(0x3a, 0x0f, "regTOn5");
  i2c_write_ioexp(0x3b, 0xff, "regTIOn5");
  i2c_write_ioexp(0x3c, 0x0f, "regOff5");
  i2c_write_ioexp(0x3d, 0x0f, "regTRise5");
  i2c_write_ioexp(0x3e, 0x0f, "regTFall5");

  // MOSFET3 - "one-shot mode" - fade off then back on when turned off
  i2c_write_ioexp(0x3f, 0x0f, "regTOn6");
  i2c_write_ioexp(0x40, 0xff, "regTIOn6");
  i2c_write_ioexp(0x41, 0x00, "regOff6");
  i2c_write_ioexp(0x42, 0x0f, "regTRise6");
  i2c_write_ioexp(0x43, 0x0f, "regTFall6");

  // MOSFET4 - fade on, fade off
  i2c_write_ioexp(0x44, 0x00, "regTOn7");
  i2c_write_ioexp(0x45, 0xff, "regTIOn7");
  i2c_write_ioexp(0x46, 0x00, "regOff7");
  i2c_write_ioexp(0x47, 0x0f, "regTRise7");
  i2c_write_ioexp(0x48, 0x0f, "regTFall7");

  // I/O pins on outputs 0-3 are on-off without fades

  uint8_t state = 0xff;
  i2c_write_ioexp(0x11, state, "regDataA");
  while (1) {
    i2c_write_ioexp(0x11, (state=~state), "regDataA");
	  vTaskDelay(10000 / portTICK_RATE_MS);
  }
}

#define GPIO_SW_BUTTON 39
#define GPIO_SW_ROT_B 36
#define GPIO_SW_ROT_A 35

#define GPIO_SW_PIN_SEL  ((1ULL<<GPIO_SW_BUTTON) | (1ULL<<GPIO_SW_ROT_A) | (1ULL<<GPIO_SW_ROT_B))
#define ESP_INTR_FLAG_DEFAULT 0

static void IRAM_ATTR pcnt_example_intr_handler(void *arg) {
	uint32_t intr_status = PCNT.int_st.val;

	for (int i = 0; i < PCNT_UNIT_MAX; i++) {
		if (intr_status & (BIT(i))) {

			if(PCNT.status_unit[i].h_lim_lat){
				printf("Hit high limit\n");
			}
			if(PCNT.status_unit[i].l_lim_lat){
				printf("Hit low limit\n");
			}
			//pcnt_counter_clear(ptr->unit);
			PCNT.int_clr.val = BIT(i); // clear the interrupt
		}
	}
}


void rotary_input() {
	gpio_pad_select_gpio(GPIO_SW_ROT_A);
	gpio_pad_select_gpio(GPIO_SW_ROT_B);
	gpio_set_direction(GPIO_SW_ROT_A, GPIO_MODE_INPUT);
	gpio_set_direction(GPIO_SW_ROT_B, GPIO_MODE_INPUT);
  gpio_pullup_en(GPIO_SW_ROT_A);
	gpio_pullup_en(GPIO_SW_ROT_B);

  pcnt_config_t r_enc_config;
  // channel 0
  r_enc_config.pulse_gpio_num = GPIO_SW_ROT_A; //Rotary Encoder Chan A
	r_enc_config.ctrl_gpio_num = GPIO_SW_ROT_B;    //Rotary Encoder Chan B

	r_enc_config.unit = PCNT_UNIT_0;
	r_enc_config.channel = PCNT_CHANNEL_0;

	r_enc_config.pos_mode = PCNT_COUNT_DIS; // PCNT_COUNT_DEC;
	r_enc_config.neg_mode = PCNT_COUNT_INC;

	r_enc_config.lctrl_mode = PCNT_MODE_KEEP;    // Rising A on HIGH B = CW Step
	r_enc_config.hctrl_mode = PCNT_MODE_REVERSE; // Rising A on LOW B = CCW Step

	r_enc_config		.counter_h_lim = 255;
	r_enc_config		.counter_l_lim = 0;

	pcnt_unit_config(&r_enc_config);

  // channel 1 - disabled for half-quad encoder
  r_enc_config.pulse_gpio_num = GPIO_SW_ROT_A; //Rotary Encoder Chan A
	r_enc_config.ctrl_gpio_num = GPIO_SW_ROT_B;    //Rotary Encoder Chan B
	r_enc_config.channel = PCNT_CHANNEL_1;
	r_enc_config.pos_mode = PCNT_COUNT_DIS; //PCNT_COUNT_INC;
	r_enc_config.neg_mode = PCNT_COUNT_DIS; //PCNT_COUNT_DEC;
	r_enc_config.lctrl_mode = PCNT_MODE_DISABLE;
	r_enc_config.hctrl_mode = PCNT_MODE_DISABLE;
	pcnt_unit_config(&r_enc_config);

  pcnt_set_filter_value(PCNT_UNIT_0, 1023);  // Filter Runt Pulses
	pcnt_filter_enable(PCNT_UNIT_0);

  /* Enable events on maximum and minimum limit values */
	//pcnt_event_enable(PCNT_UNIT_0, PCNT_EVT_H_LIM);
	//pcnt_event_enable(PCNT_UNIT_0, PCNT_EVT_L_LIM);

	pcnt_counter_pause(PCNT_UNIT_0); // Initial PCNT init
	pcnt_counter_clear(PCNT_UNIT_0);

	/* Register ISR handler and enable interrupts for PCNT unit */
  //esp_err_t er = pcnt_isr_register(pcnt_example_intr_handler,(void *) NULL, (int)0, NULL);
  //if (er != ESP_OK){
  //  printf("Encoder wrap interrupt failed\n");
  //}
  //
  //pcnt_isr_handler_add(PCNT_UNIT_0, pcnt_example_intr_handler, (void *)NULL);
	pcnt_intr_enable(PCNT_UNIT_0);
	pcnt_counter_resume(PCNT_UNIT_0);

  int16_t val=0, oldval=0;
  while (1) {
    pcnt_get_counter_value(PCNT_UNIT_0, &val);
    if (val != oldval) {
      printf("%20s %d\n", "Encoder value", val);
    }

    oldval = val;

	  vTaskDelay(100 / portTICK_RATE_MS);
  }

}

void app_main()
{
    
    for (int i=0; i<5; i++) {
      printf("Waiting to start\n");
      vTaskDelay(500 / portTICK_RATE_MS);
    }

    i2c_setup();
    num_config();
    xTaskCreate(&ioexp_config, "ioexp_config", 2048,NULL,5,NULL );
    xTaskCreate(&rotary_input, "rotary_input", 2048,NULL,5,NULL );
}

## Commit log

2020-11-23 vandal, initial commit
    Import platformio framework and PCB layout for board rev 1.0. Add a
    simple README, some board renders, and the schematic.
    [van-B.Cu.gbr, van-B.Mask.gbr, van-B.Paste.gbr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]
2020-11-23 readme, add board renders and schematic
2020-11-23 pcb, add v1.0 BOM
    [bom.csv]
2020-11-23 readme, mention the rotary encoder
2020-11-24 pcb, fix NPTH on paste layers
    The solderpaste layers incorrectly contained NPTH for mounting the
    modules, which jlcpcb picked up. Fix the two footprints and revise the
    two paste layers.
    [van.kicad_pcb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]
2020-12-11 wrangling i2c bus things - some communication working
2020-12-11 working LED driver with each mode demonstrated
    The one-shot mode seems a bit useless - it must be designed for an
    inverted output.
    [blink.c]
2020-12-13 rotary encoder, count using pulse counter module
    Use the hardware pulse counter to process the quadrature encoder.
    Examples cribbed from the ESP32 example solution.
    Note - the interrupt routine doesn't work yet (LoadProhibited crash loop
    when enabled).
    The filter value seems to need to be very high in order to miss stray
    counts.
    [blink.c]
2021-02-25 merge some maybe-broken changes to add support for the LED panel, but do not work yet.
    edit - these did work... there was a dry solder joint. Yay!
    [van.kicad_pcb]

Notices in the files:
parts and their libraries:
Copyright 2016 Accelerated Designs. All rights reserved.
